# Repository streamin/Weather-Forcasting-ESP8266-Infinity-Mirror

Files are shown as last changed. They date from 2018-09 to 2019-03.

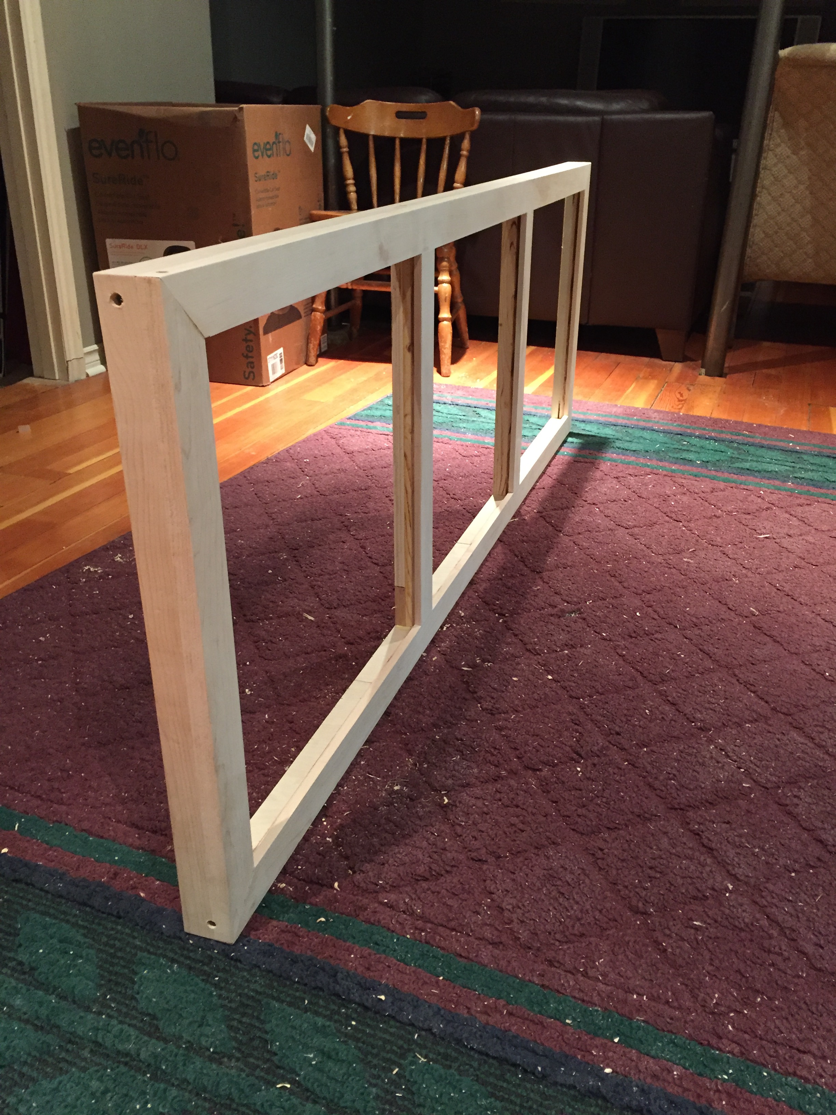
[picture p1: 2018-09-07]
Photos/2016-03-14 23.43.30.jpg

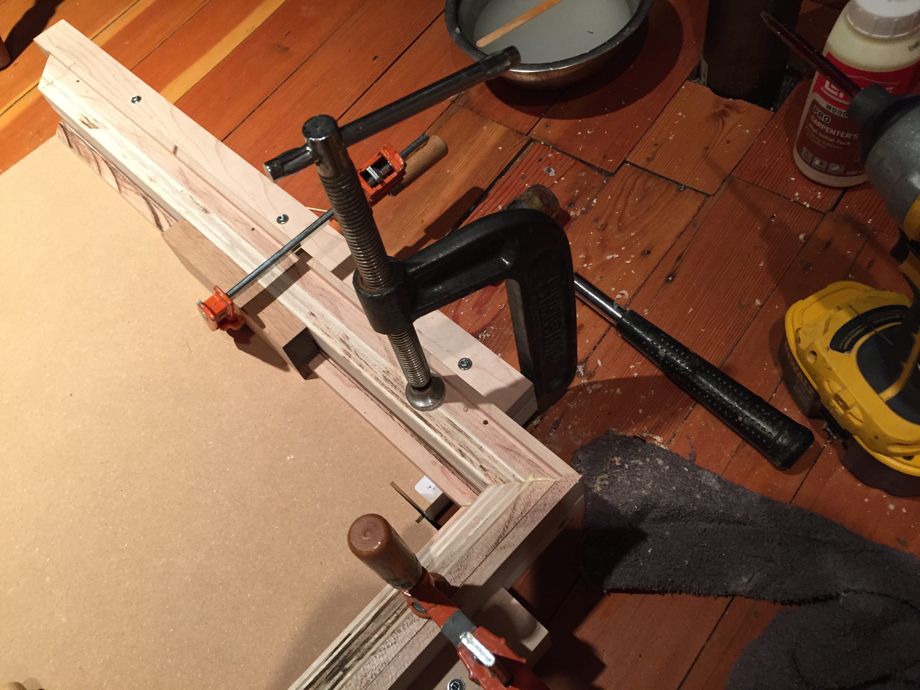
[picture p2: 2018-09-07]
Photos/2016-03-14 20.38.24.jpg

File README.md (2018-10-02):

# Weather Forcasting ESP8266 Infinity Mirror
A WiFi connected Infinity Mirror that displays current and forecasted weather information with NeoPixels. Writen with the Arduino IDE.

The infinity mirror has an arbitrary number of panes.
Each pane has an equal but arbitrary number of NeoPixels.
Each pane represents the current weather or the weather for a specified forecast period.
Weather data is from the Dark Sky API (https://darksky.net/dev/docs).

Temperature is represented by the hue of the NeoPixels.
Wind Angle is represented by a single NeoPixel whose position on the perimeter of the pane coresponds to the Wind Angle.
Wind Speed is represented by the saturation of the Wind Angle NeoPixel.
Probability of Percipitation is represented by a twinkling effect.

As the weather forecast is updated there are smooth transitions in the appearence of the NeoPixels. Temperature is relative to the seasonal averages so the hue changes frequently. Without this feature the NeoPixel hues would only change with the season.

Uses ArduionJson (https://github.com/bblanchon/ArduinoJson) and NeoPixelBus (https://github.com/Makuna/NeoPixelBus).

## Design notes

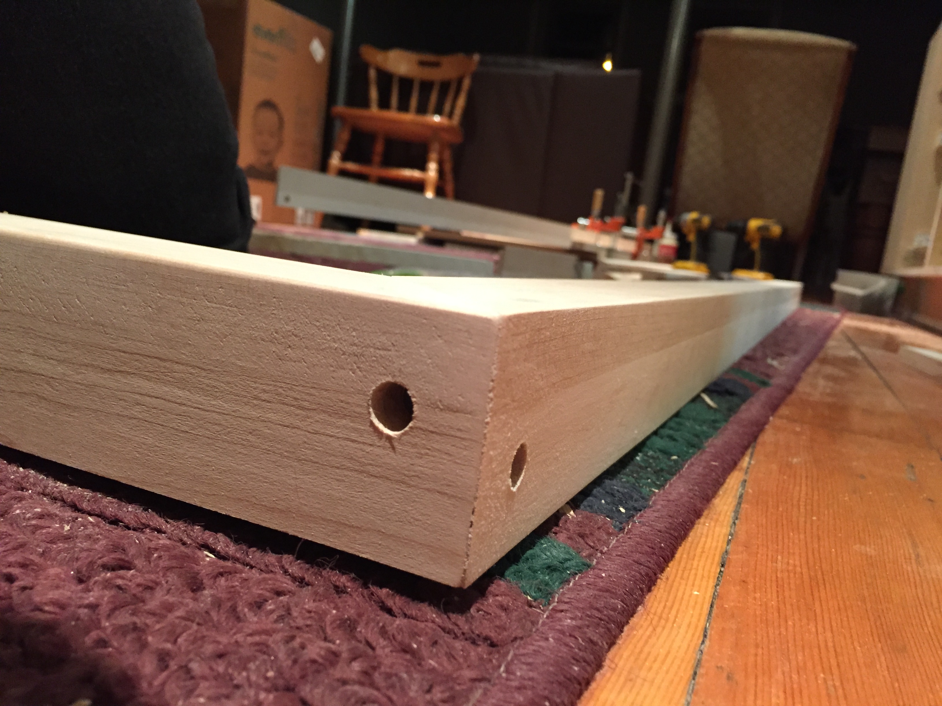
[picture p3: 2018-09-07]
Photos/2016-03-14 20.38.54.jpg

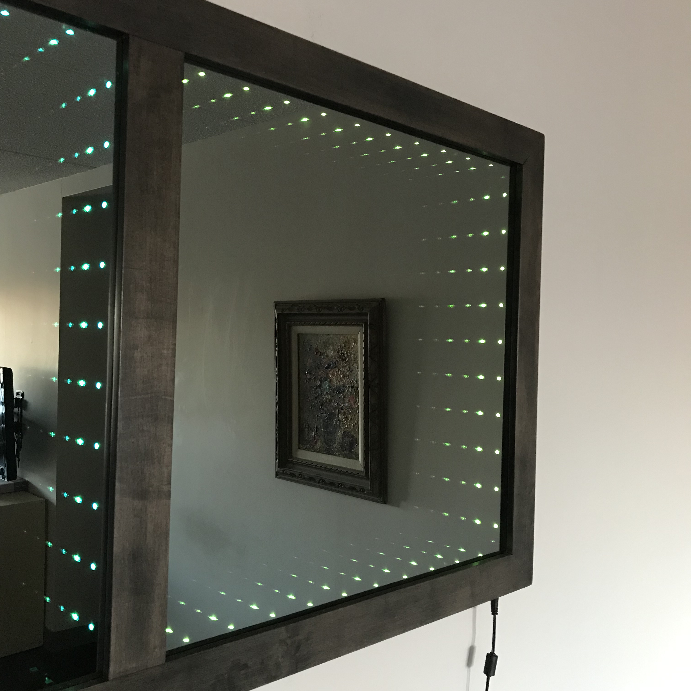
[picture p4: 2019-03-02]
Photos/2019-02-27 16.53.24.jpg

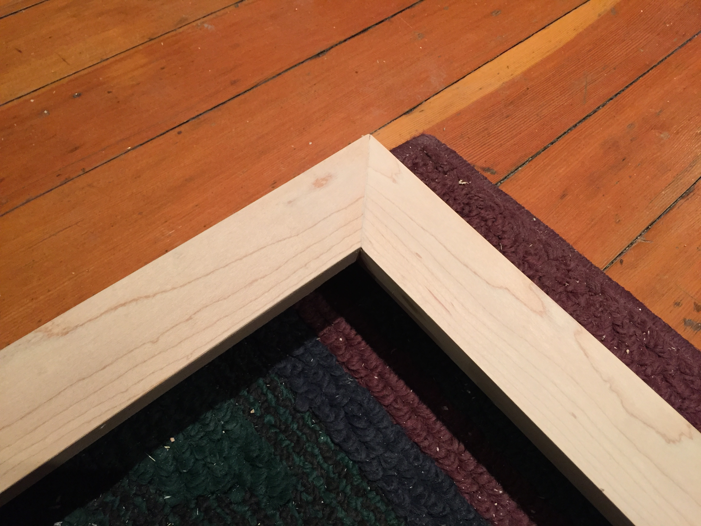
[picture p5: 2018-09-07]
Photos/2016-03-14 20.38.39.jpg

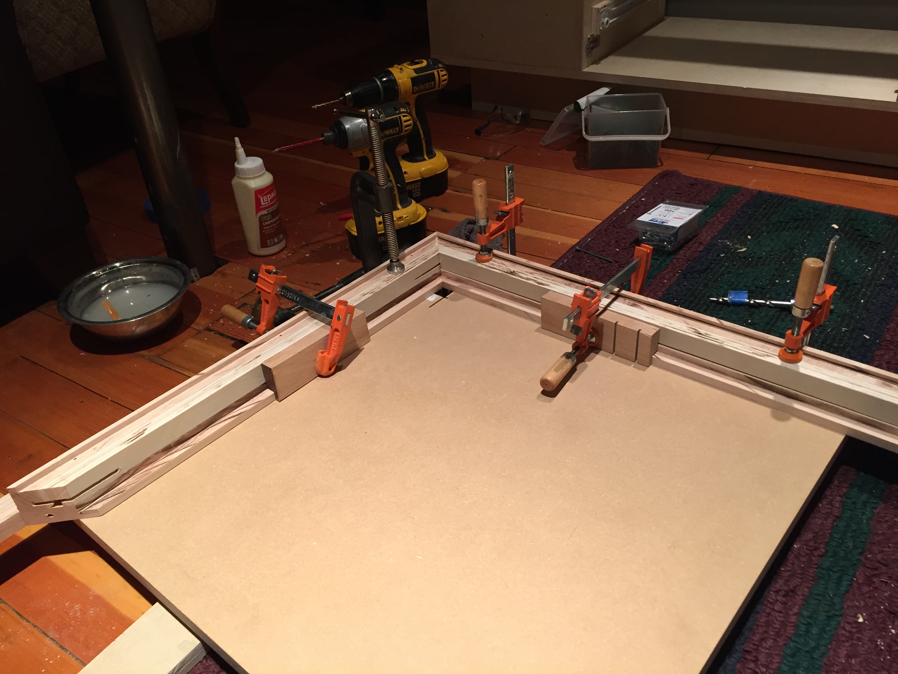
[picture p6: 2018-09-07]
Photos/2016-03-14 20.38.16.jpg

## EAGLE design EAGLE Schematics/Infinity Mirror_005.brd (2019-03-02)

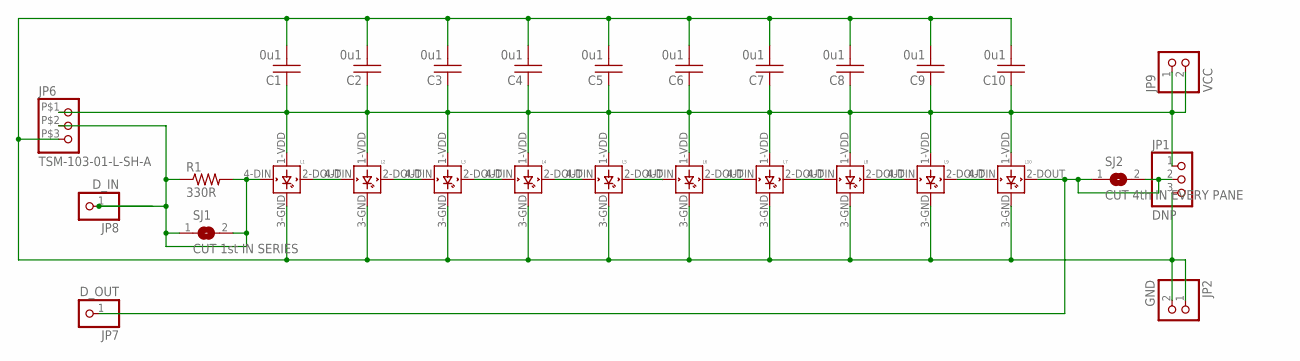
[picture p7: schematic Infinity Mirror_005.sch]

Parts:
C1, C2, C3, C4, C5, C6, C7, C8, C9, C10: 0u1; C1206
JP1: DNP; 1X03-CLEANBIG
JP2: GND; 1X02-CLEANBIG
JP6: TSM-103-01-L-SH-A
JP7: D_OUT; 1X01-CLEANBIG
JP8: D_IN; 1X01-CLEANBIG
JP9: VCC; 1X02-CLEANBIG
L1, L2, L3, L4, L5, L6, L7, L8, L9, L10: WS2812B
R1: 330R; R1206
SJ1: CUT 1st IN SERIES; SJ
SJ2: CUT 4th IN EVERY PANE; SJ

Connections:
GND: C1.2, C2.2, C3.2, C4.2, C5.2, C6.2, C7.2, C8.2, C9.2, C10.2, JP1.3, JP2.1, JP2.2, JP6.P$3 (3), L1.3-GND (GND), L2.3-GND (GND), L3.3-GND (GND), L4.3-GND (GND), L5.3-GND (GND), L6.3-GND (GND), L7.3-GND (GND), L8.3-GND (GND), L9.3-GND (GND), L10.3-GND (GND)
unnamed: L2.2-DOUT (DOUT), L3.4-DIN (DIN)
unnamed: L3.2-DOUT (DOUT), L4.4-DIN (DIN)
unnamed: L4.2-DOUT (DOUT), L5.4-DIN (DIN)
unnamed: L5.2-DOUT (DOUT), L6.4-DIN (DIN)
unnamed: L6.2-DOUT (DOUT), L7.4-DIN (DIN)
unnamed: L1.2-DOUT (DOUT), L2.4-DIN (DIN)
unnamed: L7.2-DOUT (DOUT), L8.4-DIN (DIN)
unnamed: L8.2-DOUT (DOUT), L9.4-DIN (DIN)
unnamed: JP6.P$2 (2), JP8.1, L1.4-DIN (DIN), R1.1, R1.2, SJ1.1, SJ1.2
unnamed: L9.2-DOUT (DOUT), L10.4-DIN (DIN)
unnamed: JP1.2, JP7.1, L10.2-DOUT (DOUT), SJ2.1, SJ2.2
VCC: C1.1, C2.1, C3.1, C4.1, C5.1, C6.1, C7.1, C8.1, C9.1, C10.1, JP1.1, JP6.P$1 (1), JP9.1, JP9.2, L1.1-VDD (VDD), L2.1-VDD (VDD), L3.1-VDD (VDD), L4.1-VDD (VDD), L5.1-VDD (VDD), L6.1-VDD (VDD), L7.1-VDD (VDD), L8.1-VDD (VDD), L9.1-VDD (VDD), L10.1-VDD (VDD)

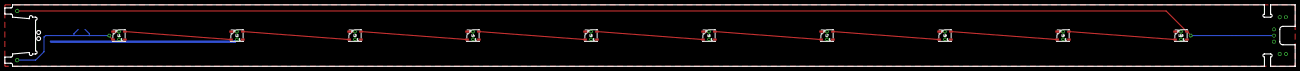
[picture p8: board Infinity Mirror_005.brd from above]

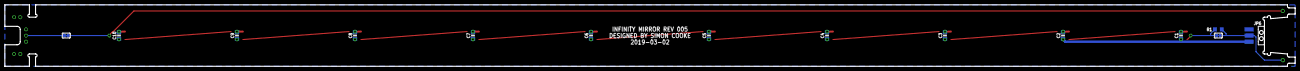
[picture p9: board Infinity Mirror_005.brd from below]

Board: 2 copper layers, 533.4 x 25.4 mm, 29 parts (14 on the bottom side), 13 nets.

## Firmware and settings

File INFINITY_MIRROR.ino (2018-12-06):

#include <ESP8266WiFi.h>
#include <WiFiClientSecure.h>
#include <ArduinoJson.h>
#include <NeoPixelBus.h>
#include "CONSTANTS.h"

//#define DEBUG

/********************************** Global Variables *******************************/
 
int16_t HueDelta[Panes]; // Hue of LEDs (temperature)
int16_t HueTarget[Panes];
int16_t HueCurrent[Panes];
int8_t  HueSign[Panes];
int16_t HueError[Panes];

int8_t  BriDelta[Panes]; // Low brightness of twinkling LEDs (rain)
int16_t BriTarget[Panes];
int8_t  BriCurrent[Panes];
int8_t  BriSign[Panes];
int16_t BriError[Panes];

int8_t  TwiDelta[Panes];  // Probability an LED will Twinkle (rain)
int16_t TwiTarget[Panes];
int8_t  TwiCurrent[Panes];
int8_t  TwiSign[Panes];
int16_t TwiError[Panes];

int8_t  SatDelta[Panes]; // Saturation of wind LED (wind speed)
int16_t SatTarget[Panes];
int8_t  SatCurrent[Panes];
int8_t  SatSign[Panes];
int16_t SatError[Panes];

int16_t AngDelta[Panes]; // Angle of wind LED (wind direction)
int16_t AngTarget[Panes];
int16_t AngCurrent[Panes];
int8_t  AngSign[Panes];
int16_t AngError[Panes];
int16_t WindLED[Panes]; // Index of wind LED

float   Temperature[Panes];  // API variables
float   WindSpeed[Panes];
float   WindBearing[Panes];
float   PrecipProb[Panes];
uint32_t UNIXTime; // int64_t will not compile. use uint32_t, will work till year 2106. int32_t will work till year 2038

int16_t TwinkleBuffer[TwinkleFrames*Panes];  // ring buffer. position in ring determines stage of twinkling
int16_t TwinkleIndex = 0;   // position in the twinkle buffer

bool FirstPass = true;

// initialize pixels
NeoPixelBus<NeoGrbFeature, Neo800KbpsMethod> strip(PixelCount, PixelPin);

/********************************** Functions **************************************/

void GetWeather() { // gets the weather from the api
  WiFiClientSecure client;

  // Connect to host
  if (!client.connect(APIHost, 443)) {
    #ifdef DEBUG
    Serial.println(F("! Connection failed !")); Serial.println();
    #endif
    return;
  }
  
  // Send GET Request
  client.print(String("GET ") + APIURL + " HTTP/1.1\r\n" +
               "Host: " + APIHost + "\r\n" +
               "User-Agent: ESP8266\r\n" +
               "Connection: close\r\n\r\n");
  
  // Timeout if no response
  uint32_t timeout = millis();
  while (!client.connected() && !client.available()) {
    if (millis() - timeout > 5000) {
      #ifdef DEBUG
      Serial.println(F("! Client timeout !"));
      #endif
      client.stop();
      return;
    }
  }
  
  if (client.find("\"currently\":")) {    // skips the headers and anything else before
    StaticJsonBuffer<jsonSize> jsonBuffer;
    JsonObject& interval = jsonBuffer.parseObject(client);
    if (interval.success()) {
      UNIXTime = interval["time"];
      int8_t j = WeatherIntervalIndex(0);  // find the index of value 0 in WeatherInterval[];
      if (j >= 0) {
        Temperature[j]  = interval["temperature"];
        WindSpeed[j]    = interval["windSpeed"];
        WindBearing[j]  = interval["windBearing"];
        PrecipProb[j]   = interval["precipProbability"];
      }
    }
  }
  
  if (client.find("\"hourly\":")) { // skips the headers and anything else before
    client.find('[');               // skips to the first item in the interval data list
    client.find("},");              // advance to the next interval because we've already addressed 0
    for (int8_t i=1; i < 49; i++) { // 1 to 48 intervals of forecast
      int8_t j = WeatherIntervalIndex(i);  // find the index of value i in WeatherInterval[];
      if (j >= 0) {
        StaticJsonBuffer<jsonSize> jsonBuffer;
        JsonObject& interval = jsonBuffer.parseObject(client);
        if (interval.success()) {
          Temperature[j]  = interval["temperature"];
          WindSpeed[j]    = interval["windSpeed"];
          WindBearing[j]  = interval["windBearing"];
          PrecipProb[j]   = interval["precipProbability"];
        }
      } else {
        client.find("},"); // advance to the next interval
      }
    }
  }
  client.stop();
  
  // deal with duplicate panes
  DuplicatePanes();

  #ifdef DEBUG
  Serial.println(F("API Data"));
  Serial.print(F("     UNIX Time: ")); Serial.println(UNIXTime);
  for (int8_t i=0; i < Panes; i++) {
    Serial.print(F(" Temperature ")); Serial.print(i); Serial.print(F(": ")); Serial.print(Temperature[i]); Serial.println(F("°C"));
    Serial.print(F("  Wind Speed ")); Serial.print(i); Serial.print(F(": ")); Serial.print(WindSpeed[i]);   Serial.println(F("m/s"));
    Serial.print(F("Wind Bearing ")); Serial.print(i); Serial.print(F(": ")); Serial.print(WindBearing[i]); Serial.println(F("°"));
    Serial.print(F("      P.o.P. ")); Serial.print(i); Serial.print(F(": ")); Serial.print(100*PrecipProb[i]);  Serial.println(F("%"));
  }
  Serial.println();
  #endif
}

int8_t WeatherIntervalIndex(int8_t element) {
  for (int8_t i = 0; i < Panes; i++) {
    if (WeatherInterval[i] == element) {
      return i;
    }
  }
  return -1;
}

void DuplicatePanes() {
  for (int8_t i = 0; i < Panes; i++) {
    for (int8_t j = i+1; j < Panes; j++) {
      if (WeatherInterval[j] == WeatherInterval[i]) {
        Temperature[j]  = Temperature[i];
        WindSpeed[j]    = WindSpeed[i];
        WindBearing[j]  = WindBearing[i];
        PrecipProb[j]   = PrecipProb[i];
      }
    }
  }
}

void FadeLEDs() {
  // For each step in the fade adjust the values of each pane
  for (int16_t j=0; j < FadeSteps; j++) {
    
    // FadeLEDs is a long blocking loop so call yield() within it
    // https://stackoverflow.com/questions/34497758/what-is-the-secret-of-the-arduino-yieldfunction
    yield();
      
    for (uint8_t i=0; i < Panes; i++) {
      // Previously this was done with interpolation but that was a whole bunch of math and it was slooooow.
      // The modified Bresenham's line algorithm is much faster.
      // Modified Bresenham's line algorithm begins. Replaced "if" with "while" so slopes greater than one can be accomadated.
      HueError[i] -= HueDelta[i];
      while (HueError[i] < 0) { HueCurrent[i] += HueSign[i]; HueError[i] += FadeSteps; }

      BriError[i] -= BriDelta[i];
      while (BriError[i] < 0) { BriCurrent[i] += BriSign[i]; BriError[i] += FadeSteps; }
      
      TwiError[i] -= TwiDelta[i];
      while (TwiError[i] < 0) { TwiCurrent[i] += TwiSign[i]; TwiError[i] += FadeSteps; }

      SatError[i] -= SatDelta[i];
      while (SatError[i] < 0) { SatCurrent[i] += SatSign[i]; SatError[i] += FadeSteps; }

      AngError[i] -= AngDelta[i];
      while (AngError[i] < 0) { AngCurrent[i] += AngSign[i]; AngError[i] += FadeSteps; }
      // Modified Bresenham's line algorithm ends

      // determine LED that indicates the angle
      int16_t Windex = 0; // wind LED index
      while (WindDirArray[Windex] < (AngCurrent[i] % 360)) {
        Windex++;
      }
      WindLED[i] = WindLEDArray[Windex]+(i*PixPerPane);
      
      // For each pixel in the pane set the base colour
      for (int16_t k=i*PixPerPane; k < (i+1)*PixPerPane; k++) {
        strip.SetPixelColor(k, HsbColor(HueCurrent[i]/360.0f, 1.0f, MaxBri/100.0f));
      }
      // Set the wind indicator LED
      strip.SetPixelColor(WindLED[i], HsbColor(HueCurrent[i]/360.0f, SatCurrent[i]/100.0f, MaxBri/100.0f));
    }
    
    #ifdef DEBUG
    Serial.print(F("Step ")); Serial.print(j+1); Serial.print(F(" of ")); Serial.println(FadeSteps);
    for (int8_t i=0; i < Panes; i++) {
      Serial.print(F("       Hue ")); Serial.print(i); Serial.print(F(": ")); Serial.println(HueCurrent[i]);
      Serial.print(F("Brightness ")); Serial.print(i); Serial.print(F(": ")); Serial.print(BriCurrent[i]); Serial.println(F("%"));
      Serial.print(F("   Twinkle ")); Serial.print(i); Serial.print(F(": ")); Serial.print(TwiCurrent[i]); Serial.println(F("%"));
      Serial.print(F("Saturation ")); Serial.print(i); Serial.print(F(": ")); Serial.print(SatCurrent[i]); Serial.println(F("%"));
      Serial.print(F("Wind Angle ")); Serial.print(i); Serial.print(F(": ")); Serial.print(AngCurrent[i]); Serial.println(F("°"));
      Serial.print(F("  Wind LED ")); Serial.print(i); Serial.print(F(": ")); Serial.println(WindLED[i]);
    }
    Serial.println();
    #endif
    
    // Twinkle the LEDs 
    for (int16_t i=0; i < FramesPerStep; i++) {
      TwinkleLEDs();
    }
  }
}

void TwinkleLEDs() {
  for (int8_t i=0; i < Panes; i++) { // for each pane
    int8_t  k = TwinkleIndex + (i*TwinkleFrames);
    
    // set the oldest pixel back to full brightness
    if (TwinkleBuffer[k] >= 0) {
      strip.SetPixelColor(TwinkleBuffer[k], HsbColor(HueCurrent[i]/360.0f, 1.0f, MaxBri/100.0f));
    }
    
    // Test if there is going to be a twinkling LED
    if (random(100) < TwiCurrent[i]) {
      // pick a new random pixel in the pane (except the wind LED) and save it to the oldest spot in the circular buffer
      do {
        TwinkleBuffer[k] = random(i*PixPerPane, (i+1)*PixPerPane);
      } while (TwinkleBuffer[k] == WindLED[i]);
    } else {
      // put a null value in the oldest spot in the circular buffer
      TwinkleBuffer[k] = -1;
    }
    
    // set the brightness of each pixel in the circular buffer. Write oldest to newest so newest overwrite oldest if there is a duplicate pixel. Oldest are the brightest, newest are the dimmest.
    for (int8_t j=1; j <= TwinkleFrames; j++) {
      k = ((j + TwinkleIndex) % TwinkleFrames) + (i*TwinkleFrames);
      if (TwinkleBuffer[k] >= 0) {
        strip.SetPixelColor(TwinkleBuffer[k], HsbColor(HueCurrent[i]/360.0f, 1.0f, ((TwinkleFrames-j)*(MaxBri-BriCurrent[i])/TwinkleFrames + BriCurrent[i])/100.0f));
      }
    }
  }

  // Advance the circular buffer
  TwinkleIndex = (TwinkleIndex + 1) % TwinkleFrames;

  // push data to LEDs
  strip.Show();

  // delay for frame period
  delay(FramePeriod);
}

void SetTargets() {
  // Determine the day of the year
  int16_t Day = (UNIXTime % 31556952)/86400; // This doesn't need to be super accurate. Leap years are accounted for in SecInYear. SecInYear = 365.2425*24*60*60 = 31556952. SecInDay = 24*60*60 = 86400.
  
  int16_t k = 1;
  while (NormalDay[k] < Day) {
    k++;
  }

  // Set seasonal temp limits
  // Interpolate between (k-1) and k
  float MaxTemp = (((Day-NormalDay[k])*1.0f) * (NormalTemp[k]-NormalTemp[k-1]) / (NormalDay[k]-NormalDay[k-1])) + NormalTemp[k];
  float MinTemp = MaxTemp - OffsetTemp;
  MaxTemp       = MaxTemp + OffsetTemp;

  #ifdef DEBUG
  Serial.println(F("Weather Limits"));
  Serial.print(F("     Day: ")); Serial.println(Day);
  Serial.print(F("Max Temp: ")); Serial.print(MaxTemp); Serial.println(F("°C"));
  Serial.print(F("Min Temp: ")); Serial.print(MinTemp); Serial.println(F("°C"));
  Serial.print(F("Max Wind: ")); Serial.print(MaxWind); Serial.println(F("m/s"));
  Serial.println();
  #endif
  
  for (int8_t i=0; i < Panes; i++) {
    // Save the previous targets as the new current values
    HueCurrent[i] = HueTarget[i];
    BriCurrent[i] = BriTarget[i];
    TwiCurrent[i] = TwiTarget[i];
    SatCurrent[i] = SatTarget[i];
    AngCurrent[i] = AngTarget[i] % 360; // AngCurrent should be between 0 and 359 until we decide if it shouldn't be
    
    // Convert temperature to hue
    // MaxTemp --> MinHue, MinTemp --> MaxHue
    HueTarget[i] = ((Temperature[i]-MinTemp)/(MaxTemp-MinTemp))*(MinHue-MaxHue) + MaxHue;
    if (HueTarget[i] < MinHue) { HueTarget[i] = MinHue; }
    else if (HueTarget[i] > MaxHue) { HueTarget[i] = MaxHue; }

    // Convert precipitation probability to brightness and twinkle probability
    // No Rain --> HiMinBri, MaxRain --> LoMinBri
    BriTarget[i] = PrecipProb[i]*(LoMinBri-HiMinBri) + HiMinBri;
    //if (BriTarget[i] > HiMinBri) { BriTarget[i] = HiMinBri; }
    //else if (BriTarget[i] < LoMinBri) { BriTarget[i] = LoMinBri; }

    // No Rain --> No Twinkle, MaxRain --> MaxTwinkProb
    TwiTarget[i] = PrecipProb[i]*MaxTwinkProb;
    //if (TwiTarget[i] > MaxTwinkProb) { TwiTarget[i] = MaxTwinkProb; }
    //else if (TwiTarget[i] < 0) { TwiTarget[i] = 0; }
    
    // Convert wind speed to saturation
    // 0kph Wind --> MaxSat, MaxWind --> MinSat
    SatTarget[i] = (WindSpeed[i]/MaxWind)*(MinSat-MaxSat) + MaxSat;
    if (SatTarget[i] > MaxSat) { SatTarget[i] = MaxSat; }
    //else if (SatTarget[i] < MinSat) { SatTarget[i] = MinSat; }

    // Convert wind bearing to wind angle
    // If the wind changes from 1 degree to 359 degress or vice-versa we want to interpolate the shortest distance around the circle: 1-->0-->359 or 359-->0-->1
    // So we add 360 to either the target or the current value: 361-->360-->359 or 359-->360-->361
    AngTarget[i] = WindBearing[i];
    if ((AngTarget[i] - AngCurrent[i]) > 180) { AngCurrent[i] += 360; }
    else if ((AngCurrent[i] - AngTarget[i]) > 180) { AngTarget[i] += 360; }

    // On the very first pass of the loop there is no starting point so we need to initialize the current values
    if (FirstPass == true) {
      HueCurrent[i] = HueTarget[i];
      BriCurrent[i] = BriTarget[i];
      TwiCurrent[i] = TwiTarget[i];
      SatCurrent[i] = SatTarget[i];
      AngCurrent[i] = AngTarget[i];
    }
    
    // *** modified Bresenham's line algorithm parameters ***
    // Determine the Deltas for the modified Bresenham's line algorithm
    HueDelta[i] = HueTarget[i]-HueCurrent[i];
    BriDelta[i] = BriTarget[i]-BriCurrent[i];
    TwiDelta[i] = TwiTarget[i]-TwiCurrent[i];
    SatDelta[i] = SatTarget[i]-SatCurrent[i];
    AngDelta[i] = AngTarget[i]-AngCurrent[i];

    // Determine the Signs for the modified Bresenham's line algorithm
    if (HueDelta[i] < 0) { HueSign[i] = -1; HueDelta[i] = -HueDelta[i]; } else { HueSign[i] = 1; }
    if (BriDelta[i] < 0) { BriSign[i] = -1; BriDelta[i] = -BriDelta[i]; } else { BriSign[i] = 1; }
    if (TwiDelta[i] < 0) { TwiSign[i] = -1; TwiDelta[i] = -TwiDelta[i]; } else { TwiSign[i] = 1; }
    if (SatDelta[i] < 0) { SatSign[i] = -1; SatDelta[i] = -SatDelta[i]; } else { SatSign[i] = 1; }
    if (AngDelta[i] < 0) { AngSign[i] = -1; AngDelta[i] = -AngDelta[i]; } else { AngSign[i] = 1; }

    // Zero the errors for the modified Bresenham's line algorithm
    HueError[i] = 0;
    BriError[i] = 0;
    TwiError[i] = 0;
    SatError[i] = 0;
    AngError[i] = 0;
  }
  
  FirstPass = false;
}

void loop() {
  ConnectWiFi();      // Check WiFi connection
  GetWeather();       // get UNIX time and weather data
  SetTargets();       // Set targets and initialize parameters for fade
  FadeLEDs();         // animate the LEDs and yeild()
}

void setup() {
  #ifdef DEBUG
  Serial.begin(115200); delay(1000);
  Serial.println(F("Fade Settings"));
  Serial.print(F("FramePeriod:   ")); Serial.println(FramePeriod);
  Serial.print(F("TwinkleFrames: ")); Serial.println(TwinkleFrames);
  Serial.print(F("MaxTwinkProb:  ")); Serial.println(MaxTwinkProb);
  Serial.print(F("FramesPerStep: ")); Serial.println(FramesPerStep);
  Serial.println();
  #endif
  
  // Set WiFi to station mode and disconnect from an AP if it was previously connected
  WiFi.mode(WIFI_STA);
  WiFi.disconnect();
  delay(100);
  ConnectWiFi(); // Check WiFi connection
  strip.Begin();
  delay(1000);
}

void ConnectWiFi() {
  if (WiFi.status() != WL_CONNECTED) {
    WiFi.begin(WiFiSSID, WiFiPSK);
    while (WiFi.status() != WL_CONNECTED) {
      #ifdef DEBUG
      Serial.print(F("."));
      #endif
      delay(500);
    }
    #ifdef DEBUG
    Serial.println(F(" WiFi connected")); Serial.println();
    #endif
  }
}

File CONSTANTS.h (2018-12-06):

// ***** WiFi Config *****
const char* WiFiSSID  = "your_ssid";
const char* WiFiPSK   = "your_password";

// ***** API Config *****
const char* APIHost = "api.darksky.net";
const char* APIURL  = "/forecast/your_api_key/latitude,longitude?exclude=minutely,daily,alerts,flags&units=si";
const int jsonSize  = 750;

// ***** Timing and Fade Config Options *****
#define       FramesPerSecond 30
const int16_t FramePeriod   = 1000/FramesPerSecond; // [ms] Refresh period of LEDs
#define       RainDropLength  750 // [ms]
const int8_t  TwinkleFrames = RainDropLength/FramePeriod; // frames for LED to resume full brightness after twinkling
#define       MaxDropsPerSec  15 // Rain drops per second at MaxRain
const int8_t  MaxTwinkProb  = MaxDropsPerSec*FramePeriod/10; // [%]  Probability an LED will twinkle at MaxRain // keep less than or equal to 100
const int16_t FadeSteps     = 10;  //
#define       APIRefreshTime  600000 // [ms] // 600,000ms = 10min between GET requests
const int16_t FramesPerStep = APIRefreshTime/(FramePeriod*FadeSteps); // Frames per fade step

// ***** Colour Settings *****
// http://colorizer.org/
// Red: 0, yellow: 60, green: 120, cyan: 180, blue: 240, magenta: 300, red: 360
const int16_t MinHue  = 0;    // colour of MaxTemp
const int16_t MaxHue  = 240;  // colour of MinTemp

const int8_t  MaxSat  = 100;  // 0 to 100, keep at 100, 0 is white, 100 is full colour
const int8_t  MinSat  = 0;    // 0 to 100, keep at 0, saturation at MaxWind

const int8_t   MaxBri  = 30;          // ~10 to ~40, tune this number to your liking
const int8_t HiMinBri  = MaxBri*0.6;  // birghtness of twinkling LED at No Rain // keep it less than MaxBri
const int8_t LoMinBri  = 0;           // birghtness of twinkling LED at MaxRain

// ***** Weather Settings *****
// We want to use relative temperature otherwise the LED colour will only change with the seasons. All values will be relative to the average value for the day of the year.
// Day 0 and 366 are Dec 31. Days are the 15th and last day of every month in a non leap year.
// http://climate.weather.gc.ca/climate_data/almanac_e.html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
const int16_t NormalDay[]   = {    0,    15,    31,    ,46,    59,   74,  ,90, 105, 120,  135,  151,  166,  181,  196,   212,  227,  243,  258,  273,  288,  304,  319,    334,   349,   366};
const float   NormalTemp[]  = {-17.3, -18.2, -16.6, -13.55, -10.6, -6.5, -1.2, 3.9, 8.3, 11.9, 14.9, 17.0, 18.6, 19.6, 19.85, 18.9, 15.9, 12.3, 9.25, 5.75, 0.45, -5.2, -10.25, -14.4, -17.3}; // [°C]
const float   MaxWind       = 8.33; // [m/s] // https://winnipeg.weatherstats.ca/charts/wind_speed-monthly.html
const int8_t  OffsetTemp    = 15;    // [°C] degrees to offset normal seasonal temperature
const int8_t  WeatherInterval[] = {24, 12, 0};  // Forecast interval shown on each pane. 0 is current weather. Repeats allowed, any order allowed. Intervals are 1 hour each.

// ***** Hardware Config Settings *****
const int8_t  PixPerPane    = 40;  // pixels per pane
const int8_t  Panes         = sizeof(WeatherInterval);
const int16_t PixelCount    = Panes*PixPerPane;
const int8_t  PixelPin      = 2; // I used the Adafruit HUZZAH. I had to remove the diode protecting the 3V3 RX pin from 5V signals. The RX pin needs to be used as an output because it is the only DMA output on an ESP8266. Labeled Pin 2 on the HUZZAH.
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

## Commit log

2018-09-07 Update and rename empty to about schematics
2018-09-07 Update and rename schematics/about schematics to EAGLE Schematics/About
2018-09-07 Rename schematics/Infinity Mirror_002.brd to EAGLE Schematics/Infinity Mirror_002.brd
    [Infinity Mirror_002.brd]
2018-09-07 Rename schematics/Infinity Mirror_002.sch to EAGLE Schematics/Infinity Mirror_002.sch
    [Infinity Mirror_002.sch]
2019-03-02 Add files via upload
    LED PCB strip for 20"x20" infinity mirror pane. Socket for glass and PCB assembly should be 21"x21".
    [Infinity Mirror_005.brd, Infinity Mirror_005.sch]
